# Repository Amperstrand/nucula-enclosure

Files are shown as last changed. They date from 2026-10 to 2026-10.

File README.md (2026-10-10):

# Nucula Enclosure — Rev 1 (no display / no keypad, optional pop-out screen)



Parametric, 3D-printable enclosure for the **Nucula board** (zeugmaster/nucula-board).
The KiCad board file is the single geometric authority: every board dimension in
this project is parsed from `nucula-v2.kicad_pcb` / its footprint libraries —
nothing is hand-transcribed.

Built with the methodology of the
[`Amperstrand/lilygo-a7670-simhat-carrier`](https://github.com/Amperstrand/lilygo-a7670-simhat-carrier/blob/cad/combined-carrier-v1/AGENTS.md)
project (its AGENTS.md lessons): measure first, boolean-volume
validation as the pass gate, calibration coupon before any real print,
renders are never evidence.

## Status (see `analysis/` for the machine-readable truth)

| Item | Status |
|---|---|
| Boolean validation | **80 / 80 checks PASS** (`analysis/interference_report.json`) |
| Deterministic rebuild | PASS (hash-identical STL on rebuild) |
| Physical print feedback | **NOT closed** — print `V0` coupon first |
| RF / battery measurements | **NOT taken** — `docs/MEASUREMENTS_NEEDED.md` |

## Variants (all from one parameter set — `cad/parameters.py`)

| Variant | Parts | Purpose |
|---|---|---|
| **V0** | `V0_calibration_coupon` | **Print FIRST.** Pilot-hole ladder, board-thickness stairs, real lip-bite bay, wire-lane slits, pop-out bridge feel |
| **V1** | `V1_bottom_shell` + `V1_lid_closed` | No screen, no keyboard (board broken away). Accessible USB-C + battery service bay |
| **V2** | `V1_bottom_shell` + `V2_lid_screen_popout` | Same print as V1's bottom; lid with a **pop-out OLED window printed closed** — pop it only if you fit the display glass |
| **V3** | `V3_bottom_shell_full` + `V3_lid_keyboard_blister` | Keyboard breakaway **NOT removed** (60×110 board). J3 keypad-header service blister with its own pop-out hatch |
| **V4** | `V4_bottom_shell_terminal` + `V4_lid_terminal` | **Payment terminal**: slim screen zone (landscape OLED window) + flared keypad zone with a bay that seats the Adafruit-1824-class 3×4 matrix keypad (70×50×7) over the breakaway section; J3 service opening in the bay floor |

Renders: `output/renders/OPTIONS_overview.png` (plus per-view PNGs and
`detail_*.png` close-ups). Renders illustrate; they are not evidence.

## Print order

1. `V0_calibration_coupon.stl` — calibrate (docs/printing.md)
2. `V1_bottom_shell.stl` + `V1_lid_closed.stl`
3. (optional) `V2_lid_screen_popout.stl`
4. (optional) `V3_bottom_shell_full.stl` + `V3_lid_keyboard_blister.stl`
5. (optional) `V4_bottom_shell_terminal.stl` + `V4_lid_terminal.stl` —
   payment-terminal layout: landscape screen on top, keypad bay (seats the
   Adafruit-1824-class 3x4 matrix keypad, 70x50x7) below over the breakaway
   section; J3 service opening in the bay floor.

## Regenerate everything

```sh
python3 scripts/extract_kicad_geometry.py   # KiCad -> analysis/*.json
python3 scripts/validate.py                 # 80 boolean checks -> interference_report.json
python3 scripts/build.py                    # STEP + STL -> output/exports
python3 scripts/render.py                   # PNG renders -> output/renders
```

Requires: Python 3.11+, `cadquery` ≥ 2.6 (2.8 verified — `requirements.txt`),
`playwright` + chromium (renders only).

**Portability:** the extracted geometry (`analysis/*.json`) is committed, so
`validate.py` / `build.py` work out of the box. Re-extraction from KiCad
needs the hardware repo: `NUCULA_REPO=/path/to/nucula-board
python3 scripts/extract_kicad_geometry.py` (defaults to
`~/my-project/reference-repos/nucula-board`).

## Layout

```
cad/parameters.py     ALL parameters + provenance tags + variant configs
cad/reference.py      board solids, component solids, keepouts, envelopes, wire sweep
cad/shell.py          bottom shell, lid (closed/popout/kb_blister), coupon
scripts/              extract / validate / build / render
analysis/             pcb_geometry.json, component_geometry.json,
                      interference_report.json, testing_status.json
output/exports/       STEP + STL per part
output/renders/       PNG renders + options overview
docs/                 design_spec, geometry_provenance, assembly, printing,
                      MEASUREMENTS_NEEDED, engineering_audit
reference/            ESP32 STEP (from the Nucula repo), three.js for renders
```

## Hard rules baked into the design

* The routed cut edge (v = 73) is **located, never clamped** — two stop ribs
  face the factory-routed windows *between* the mouse-bite remnant zones;
  the remnant envelope (2.0 mm stub + 0.30 mm spread) stays clear.
* **No metal anywhere.** Snap-fit lid (4 tabs), plastic plungers over
  RESET/BOOT, no inserts — nothing metallic near the NFC coil or the
  ESP32-C3 antenna.
* NFC: shell faces over the coil are ≤ `NFC_WALL_T` (1.6 mm); no structure
  above the coil plane inside the PCB's own antenna rule areas.
* Battery: pocket in the floor *behind* the ESP32/USB end (clear of the coil),
  swell clearance, wire route leaves the JST rear exit and drops through the
  remnant channel — all boolean-checked.
* USB-C: opening admits a fully-seated 13.0 × 6.5 mm plug envelope plus
  cable-bend service void — zero shell material inside it.

If you find a mechanical blocker in the *board*, do not "fix" it here —
record it in `docs/MEASUREMENTS_NEEDED.md`. The PCB is not modified by this
project.
## Photoreal hero render

Watch the V4 payment terminal assemble itself and spin:
**[nucula_hero.mkv](https://github.com/Amperstrand/enclosure-media/blob/main/nucula_hero.mkv)**
(+ stills) in [`Amperstrand/enclosure-media`](https://github.com/Amperstrand/enclosure-media) —
headless Blender/Cycles on GPU, built from these validated exports.

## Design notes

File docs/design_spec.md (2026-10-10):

# Design specification & audit — Nucula enclosure rev 1

Design intent in words, then the audit evidence for every sentence.
Evidence: `analysis/interference_report.json` (**57/57 PASS**, this run)
+ `analysis/testing_status.json`.

## Spec

1. **The unit houses one Nucula main PCB (keyboard breakaway removed,
   60 × 73 mm) or the full 60 × 110 board — never both at once.**
   Audit: `seated_board_bottom_interference = 0` for V1/V2 (main) and V3
   (full) beyond named lip contacts; `component_clearance` clean for all
   100+ placed parts in each mode.
2. **The board rests in a tray captured by retention lips on the three
   factory edges (u=0, u=60, v=0) and located — not clamped — at the
   routed cut edge by two stop ribs.**
   Audit: lips are the only board/bottom contact (INTENDED, subtracted);
   `cut_edge_located_not_clamped` (0.30 mm rib gap);
   `remnant_clearance = 0` (0.30 mm spread around every tab/bridge stub).
   No screws touch the board: it has no mounting holes, and every corner
   is adjacent to antenna/connector zones — snap-fit lid instead.
3. **NFC first.** Nothing metallic exists anywhere in the enclosure; shell
   faces over the 40 × 40 coil are ≤ 1.6 mm; no structure above the coil
   plane inside the PCB's own antenna rule areas.
   Audit: `nfc_battery_clear = 0`, `nfc_no_structure_over_coil = 0`,
   `nfc_reading_path_thin` (floor 1.4 / roof 1.4 / wall 1.6 ≤ NFC_WALL_T).
   Deliberate, documented: V2's glass hovers part of the rule area
   (dielectric) — `screen_glass_nfc_disclosure` + measurement item.
4. **ESP32-C3 antenna gets air.** The module's overhang clears through an
   open wall window (u 60.2..61.95, v 47..65.3, z 1.6..7.0); no battery or
   wiring in the antenna zone.
   Audit: `esp32_keepout_clear` (battery 0 / wires 0).
5. **USB-C accepts a fully seated common cable.** Opening = 13.0 × 6.5 mm
   plug envelope + 0.6 mm clearance + external lead-in chamfer; plug +
   overmold + cable-bend void (26 mm reach) contains zero shell material.
   Audit: `usb_envelope_clear = 0`, `usb_opening_size` (14.2 × 7.71 mm).
6. **The battery connector stays serviceable without tools.** A service bay
   in the left wall (46.3..54.2 v-band) exposes the JST PH housing; the
   lid snaps off; the battery pocket lives in the floor behind the
   ESP32/USB end, clear of both antennas, with swell + wire headroom.
   Audit: `battery_seat_clear = 0`, `wire_route_clear = 0` (JST housing
   contact INTENDED).
7. **Screen option is a printing decision, not a redesign.** V2's lid
   prints with the window closed behind a 1.0 mm pop-out panel (4 bridges
   + pick notch); pop it only when fitting the glass.
   Audit: `popout_panel_intact`, `screen_glass_fits` (0 part contact).
8. **Keyboard-attached variant keeps the future open.** V3 adds 37 mm of
   body, a factory-edge stop, and a J3 service blister with a pop-out
   hatch sized for a 1×9 2.54 mm header (8.7 mm).
   Audit: `j3_header_fits_blister = 0` with the header fitted.
9. **Prints flat, support-free, in PETG on a ~220 mm bed.** Largest part
   64.8 × 115.6 × 15.8 mm. Lid prints exterior-face-down (the pop-out
   panels and bridge walls print on the bed; the 1.7 mm roof step is the
   only small bridge).
10. **Every dimension is parametric and the model regenerates
    deterministically.** Audit: `build:deterministic_rebuild` PASS.

## V4 payment terminal (2026-10-10)

Layout: **screen on top, keypad below** (user directive; nucula-board
device orientation). The keypad is the board's intended peripheral: an
Adafruit-1824-class 3x4 matrix keypad (official outline 70x50x7, 7 scan
lines onto J3 pins 2-8; nucula-board keyboard-interface.md cites the
Adafruit 3845 arrangement).

Why a flared keypad zone instead of a flush cutout (elimination, all
boolean-probe driven):

* A flush through-cutout needs the keypad body (7 mm) INSIDE the cavity.
  The bottom zone has no 51 mm clean vertical span: J1 (USB, v 56..67,
  top z 6.7) and J3 + pigtail (v 104..111, top z ~12.1) bound it. A
*shallow* recess deeper than the 1.2 mm blister roof cuts into the J3
void. So the keypad sits OUTSIDE, in a bay: podium interior 12.4 mm
(clears J3 8.7 + pigtail), bay floor slab 1.4 mm, bay recess 3.0 mm.
* The 70 mm keypad exceeds the 64.75 mm slim case: the keypad zone
  flares +4.85 mm per side (outer 75.45) from the routed cut edge band
  (v 73.6) — vertical seam faces only, prints with the shell.
* Bay: u -5.6..65.6 (70 + 2x0.6 slack), v 58.8..110.0; rim 1.6; keys
  stand 4.0 mm proud of the rim (terminal look). Service opening
  u 18..42 x v 103.5..110 through the bay floor gives J3 tool access +
  the pigtail drop-through (no hatch needed: remove keypad to service).

Keypad geometry source: official Adafruit 1824 outline (datasheet text +
dimension drawing in the repo). A downloadable STEP of this exact part
exists (GrabCAD "adafruit-3x4-phone-style-matrix-keypad-1") but every
download path is login-gated; the render/validation stand-in uses ONLY
the official outline + a conservative 3x4 key grid, disclosed in
geometry_provenance.md. Replace with the real model when a login session
is available; the bay dimensions do not depend on it.

New checks (80 total): V4 runs the full matrix + `keypad_bay_admits_
stand-in` (official-outline solid seats without wall contact) +
`j3_service_opening_clear`.

## Known gaps (deliberate, documented)

- No physical print feedback yet — this release exists to close it (coupon first).
- Battery cell is a documented placeholder (30 × 22 × 6.0 mm).
- OLED glass outline/flex are conservative assumptions pending measurement.
- NFC range is the hardware repo's own open item; the enclosure adds a
  measured-later reading path (≤1.6 mm PETG everywhere over the coil).

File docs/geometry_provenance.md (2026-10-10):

# Geometry provenance

Every number used by the enclosure, and where it came from. Classes:
**extracted_kicad** (parsed from `nucula-v2.kicad_pcb` / footprint libs),
**derived_kicad** (computed from extracted geometry), **manufacturer_doc**
(Nucula repo doc or component drawing), **conservative_assumption**
(documented guess — measure before rev 2), **enclosure_design_decision**
(our choice — a changeable parameter).

## Board (all extracted_kicad / derived_kicad)

| Quantity | Value | Source |
|---|---|---|
| Outline | 60.000 × 110.000 mm | Edge.Cuts stitch, cross-checks docs/keyboard-breakaway.md |
| Thickness | 1.60 mm | `(general (thickness 1.6))` |
| Coordinate origin | KiCad (50, 50) = local (u0, v0) | derived from outline bbox |
| Main section | v 0..73 | routed gap edge (Edge.Cuts), matches keyboard-breakaway.md |
| Gap | v 73..75, corner r = 4 at both ends | Edge.Cuts |
| Support tabs | u 8.75..15.25 and 44.75..51.25 (rounded ends) | Edge.Cuts point-in-polygon |
| Central bridge | u 27.25..32.75 | inner slot boundaries |
| ESP32 antenna notch | u 55..60 × v 47.14..65.14 (18 × 5) | Edge.Cuts |
| Outer corner radii | r = 4 (all four corners) | Edge.Cuts arcs |

## Key components (bbox = pads+courtyard, derived_kicad)

| Ref | Part | u-extent | v-extent | Height | Height provenance |
|---|---|---|---|---|---|
| J1 | GCT USB4105-GF-A (USB-C) | −0.79..8.15 (shell face −0.80) | 56.42..67.36 | 3.31 | manufacturer_doc: GCT drawing |
| J2 | JST PH B2B-PH-SM4-TB | housing 2.39..10.0 (silk) | 46.82..54.98 | 5.60 | manufacturer_doc: JST drawing |
| DS1 | Hirose FH12A-24S-0.5SH | 21.2..38.8 | 53.6..61.6 | 2.00 | manufacturer_doc: Hirose drawing |
| U3 | ESP32-C3-WROOM-02-N4 (repo STEP) | 41.0..61.0 (antenna trace 54.92..60.57 overhangs the notch) | 47.14..65.14 | 3.20 | extracted_kicad: STEP bbox |
| U8 | PCF8574T (SOIC-16W) | 4.22..16.08 | 92.69..103.50 | 2.70 | conservative_assumption |
| J3 | 1×09 2.54 header (DNP) | 18.07..41.93 | 105.73..109.27 | 8.70 if fitted | conservative_assumption |
| SW1/SW2 | Omron B3U-1000P (RESET/BOOT) | centres (56.5, 34.0) / (56.5, 29.0) | — | 1.80 | conservative_assumption |
| D3 | Charge LED (0603) | centre (15.5, 44.0) | — | 0.70 | conservative_assumption |
| U1 | TP4054 (SOT-23-5) | 11.45..15.55 | 49.80..53.20 | 1.45 | conservative_assumption: JEDEC max |
| A1 | NFC coil (etched copper) | 10.75..50.75 | 1.00..41.00 | 0.035 | manufacturer_doc: 40×40 footprint property; cross-checked vs PCB rule areas |

## Keepouts / envelopes

| Zone | Extent | Provenance |
|---|---|---|
| NFC keepout | u 8.25..53.25 × v −1.5..43.5, all z | extracted_kicad: PCB antenna rule areas (verbatim) |
| ESP32 antenna keepout | u 52.0..61.5 × v 44.0..68.34, all z | derived_kicad trace bbox + 2.9 mm metal margin |
| USB plug envelope | mating face u −0.8, reach 26 mm, 13.0 × 6.5 plug | manufacturer_doc (GCT "6.5 Max", 12.x plug) + design decision |
| Battery pocket | u 7..55.6 × v 45.8..71.9, z −5.3..1.2 | enclosure_design_decision |
| Screen window (V2) | glass u 1.25..58.75 × v 16.6..46.0, LANDSCAPE, flex edge (+v short edge) folds ~12.9 mm to DS1 (24-pad row along u, panel pin 1 left / pin 24 right) | enclosure_design_decision + nucula-board device orientation (screen top, keyboard underneath); raised 2026-10-09 for the payment-terminal layout; NFP1309-02Y contact-edge side unverified |
| Remnant envelope | 3 stub zones + 0.30 spread, v 73..75.2 | enclosure_design_decision |

## Battery wire route (enclosure_design_decision)

J2 rear exit (u 10.0, v 50.9 ± 0.65, z = board_top + 2.0 per JST drawing)
→ −v corridor (J2 housing vs U1) → z 7.0 lane at u 19.2/20.6 (east of Q1,
west of the stop ribs, between remnant zones) → drop through the remnant
channel (v 73.58..75.08) → under-board run at z 0.78 → battery terminals.
Full-board mode: same start, z 7.0 over the whole keyboard section, drop
through the 2.0 mm channel at the factory edge v = 110.

## Heights not in the table

All unlisted SMD bodies use 1.00 mm (conservative_assumption: generic
passives ≤ 1.0). Change `COMP_HEIGHTS` in `cad/parameters.py` if your
build uses taller parts; the validator re-checks everything.

## V4 keypad (payment terminal)

| Quantity | Value | Source |
|---|---|---|
| Keypad class | Adafruit 1824/3844-class 3x4 matrix, 7 lines | manufacturer_doc + nucula-board docs/keyboard-interface.md |
| Outline | 70.0 x 50.0 x 7.0 mm, 23 g | manufacturer_doc: Adafruit 1824 datasheet |
| Key grid (stand-in only) | 3 cols x 4 rows, 10.8x9.2 caps +1.5 domes | conservative_assumption (render stand-in; official model download is login-gated - GrabCAD adafruit-3x4-phone-style-matrix-keypad-1) |
| Bay | u -5.6..65.6 x v 58.8..110.0, 3.0 deep | enclosure_design_decision (outline + 0.6 slack) |
| Zone flare | +4.85/side from v 73.6 (outer 75.45) | enclosure_design_decision |
| Podium interior | 12.4 (J3 8.7 + 0.5 + pigtail headroom) | enclosure_design_decision |
| J3 service opening | u 18..42 x v 103.5..110 in bay floor | enclosure_design_decision |

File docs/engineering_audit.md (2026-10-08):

# Engineering audit — requirement traceability

Method: boolean common-volume checks against the KiCad-derived reference
model (`analysis/interference_report.json`, 57/57 PASS). "mm³" = unexpected
common volume after subtracting named INTENDED contacts.

| # | Requirement | Verdict | Evidence |
|---|---|---|---|
| 1 | First build the authoritative PCB mechanical model from KiCad; no hand-transcribed dimensions | **met** | `scripts/extract_kicad_geometry.py`; 60×110 outline, 1.6 thickness, 131 footprints, tab/bridge/notch topology all parsed; cross-checked vs docs (keyboard-breakaway.md, nfc-antenna.md) |
| 2 | Main PCB = board after keyboard separation (~60×73) — verified programmatically | **met** | Edge.Cuts point-in-polygon: main section v 0..73; tabs/bridge remnant zones mapped |
| 3 | Keep KiCad orientation as the global frame | **met** | board-local (u,v) = KiCad (X−50, Y−50); transform documented in extract script |
| 4 | No OLED window, no keypad openings in the base design | **met** | V1 lid closed; V2 window is an optional pop-out (user decision); V3 hatch is service-only |
| 5 | Cut edge never used for tight location; prefer factory edges | **met** | stop ribs at 0.30 mm gap facing routed windows between remnant zones; v=0/u/u=60 edges + pocket rim carry the rest |
| 6 | PCB retention without mounting holes; no force on parts/solder/USB/battery/NFC | **met** | 3-edge lips (0.65 overhang, INTENDED contact), 4 corner under-board pads on bare laminate, pocket rim locators, stop ribs; `seated_board_*` + `component_clearance` = 0 |
| 7 | NFC keepout: 3D, no battery/screws/inserts/magnets/metal above or behind the coil | **met** | `nfc_battery_clear`, `nfc_no_structure_over_coil`, snap-fit + plastic plungers; disclosure: V2 glass partially overlays the rule area (dielectric, measured later) |
| 8 | Thin wall adjacent to coil (NFC_WALL_T, 1.2–2.0) | **met** | all shell faces over the coil ≤ 1.6 (`nfc_reading_path_thin`) |
| 9 | ESP32 antenna keepout, plastic-only | **met** | `esp32_keepout_clear`; plus an open wall window so the overhang clears |
| 10 | Battery: conservative placeholder, swell allowance, wide pocket (no point clamps), wire routing without pinch, away from both antennas | **met** | pocket 47.5×26.1×7.5 void for a 30×22×6 cell; `battery_seat_clear`, `wire_route_clear`, `esp32_keepout_clear`, `nfc_battery_clear` |
| 11 | USB-C real mating envelope, full insertion, zero intersection, external chamfer, wall strength | **met** | `usb_envelope_clear = 0`, `usb_opening_size` (14.2 × 7.71), lead-in chamfer, bay is wall-local |
| 12 | Buttons: derive function, then regular access or tool hole | **met** | SW1 RESET / SW2 BOOT (net-derivable, BOM value) → recovery use → Ø3.2 ports + moulded plastic plungers |
| 13 | Fastening: simplest reliable, metal away from antennas, boss clearances verified | **met (deviation documented)** | snap-fit lid chosen OVER screws: the board has no holes, all four corners are antenna/connector-adjacent, and boss shafts could not clear the corner voids (r4) without two-tier posts. Screws would violate "metal away from antennas" or need bosses inside component zones. Coupon retains a pilot ladder if a future rev wants screws |
| 14 | Coupon reuses production geometry | **met** | `shell.coupon()` consumes RAIL_LIP_*, SCREEN_BRIDGE_*, slit ladder |
| 15 | Automated validation incl. INTENDED/FAILURE classification | **met** | 57 checks; intended contacts named (lips, J2 wire exit, plunger hover); deterministic-rebuild check included |
| 16 | Renders as illustrations, close-ups for feature verification | **met** | `output/renders/OPTIONS_overview.png` + 15 per-view PNGs + 5 detail PNGs |
| 17 | Machine-readable reports | **met** | `interference_report.json`, `testing_status.json`, `parts_manifest.json`, `render_manifest.json` |
| 18 | Deliver STEP + STL + docs | **met** | `output/exports/*.step|stl` (8 parts), this docs set |
| 19 | Variants: calibration / minimal (USB+battery access) / screen pop-out / keyboard-attached | **met** | V0/V1/V2/V2b/V3 all built, validated, rendered |
| 20 | Testing status visible everywhere | **met** | `testing_status.json` + README matrix: boolean-verified vs requires-physical-print vs requires-measurement |
| 21 | PCB not modified; blockers recorded, not "fixed" | **met** | `docs/MEASUREMENTS_NEEDED.md` board-side section |
| 22 | Reusable architecture for future revs (display/keypad versions) | **met** | parameters + provenance + validation framework are variant-driven; `screen_window`/`kb_blister` flags already implement the extension points |

## Deviations from the original brief (documented)

1. **Snap-fit instead of screws** (req. 13): reasons above; reversible by
   setting `SCREW_*` params and re-adding posts in a rev-2 branch.
2. **ESP32 antenna wall window**: brief said "plastic-only in the zone" —
   the open slot goes further (air path) because the module overhangs the
   board edge by 1.0 mm and a closed 1.6 mm wall would collide; RF-wise
   it is the better reading environment. Measure (item 7).
3. **Battery under the board, connector end** (not beside the board):
   keeps the case 60 mm wide (wallet-like); the wire route threads the
   JST rear exit, the remnant channel and the under-board gap — all
   boolean-verified. If the real cell exceeds 30 × 22 × 6, the pocket
   grows and the case thickens — parameters handle it.

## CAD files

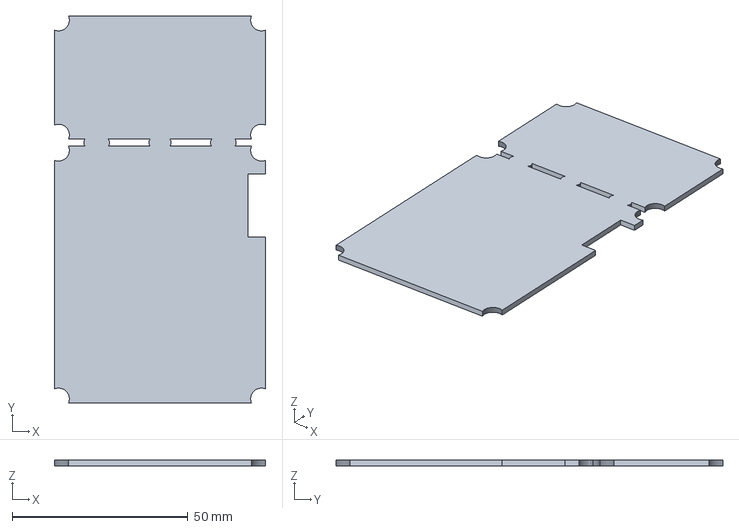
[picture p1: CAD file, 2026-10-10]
output/exports/reference_full_board.step
60.0 x 110.0 x 1.60 mm

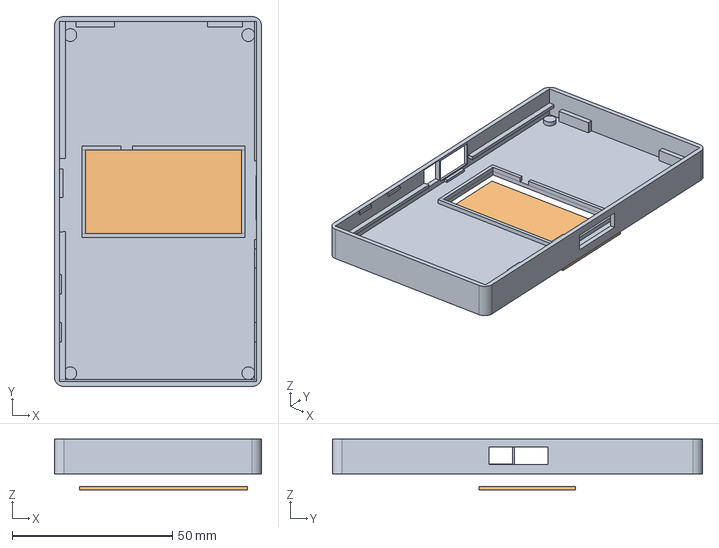
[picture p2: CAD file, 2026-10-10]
output/exports/V3_bottom_shell_full.step
64.8 x 115.5 x 15.8 mm

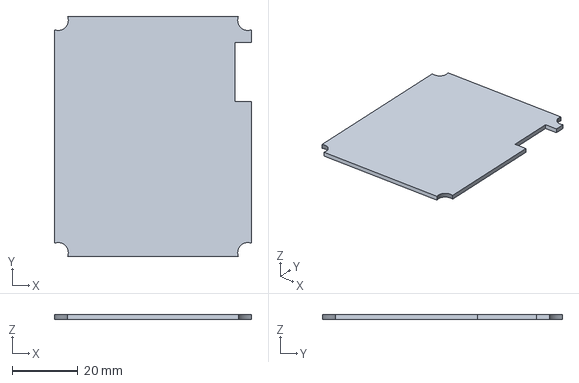
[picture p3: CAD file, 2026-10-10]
output/exports/reference_main_board.step
60.0 x 73.0 x 1.60 mm

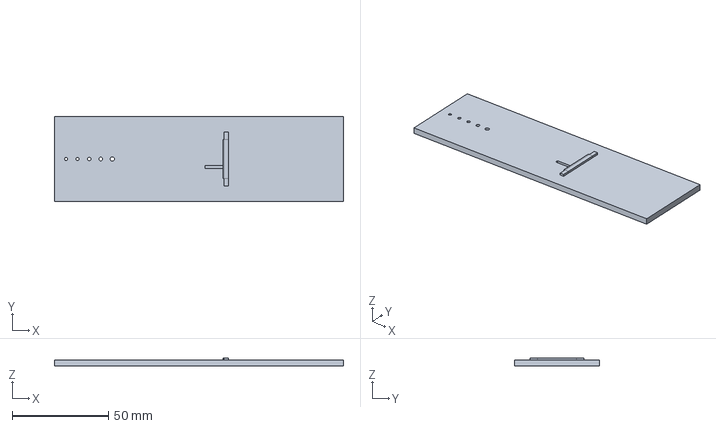
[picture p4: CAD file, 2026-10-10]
output/exports/V0_calibration_coupon.step
150.0 x 44.0 x 4.30 mm

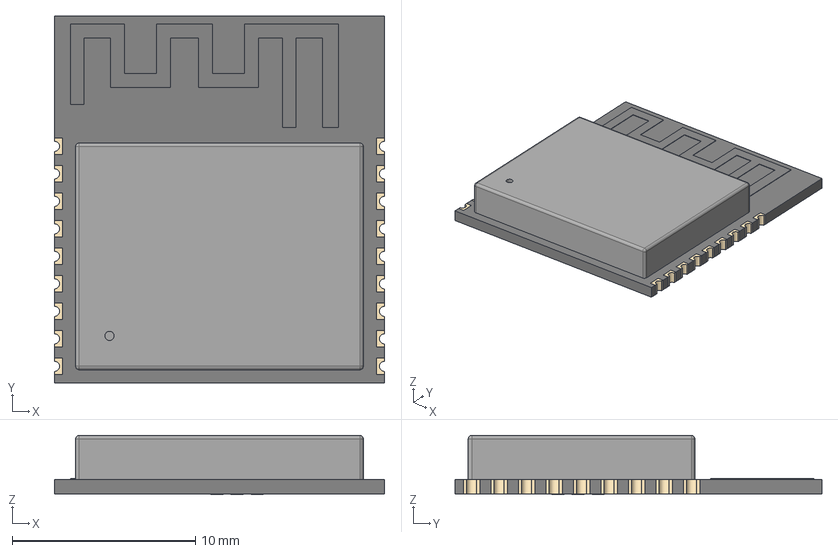
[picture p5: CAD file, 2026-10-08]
reference/ESP32-C3-WROOM-02-N4.step
18.0 x 20.0 x 3.24 mm

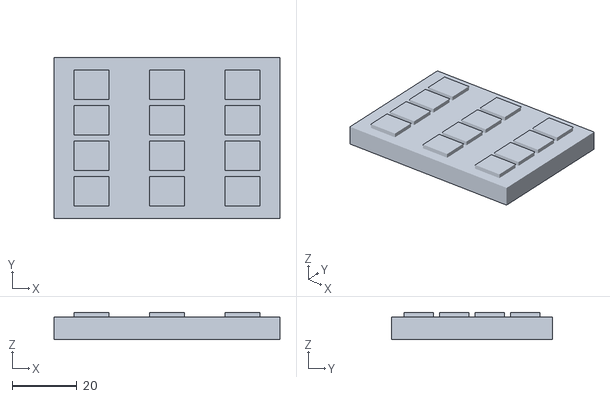
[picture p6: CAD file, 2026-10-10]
output/exports/keypad_standin.stl
70.0 x 50.0 x 8.50

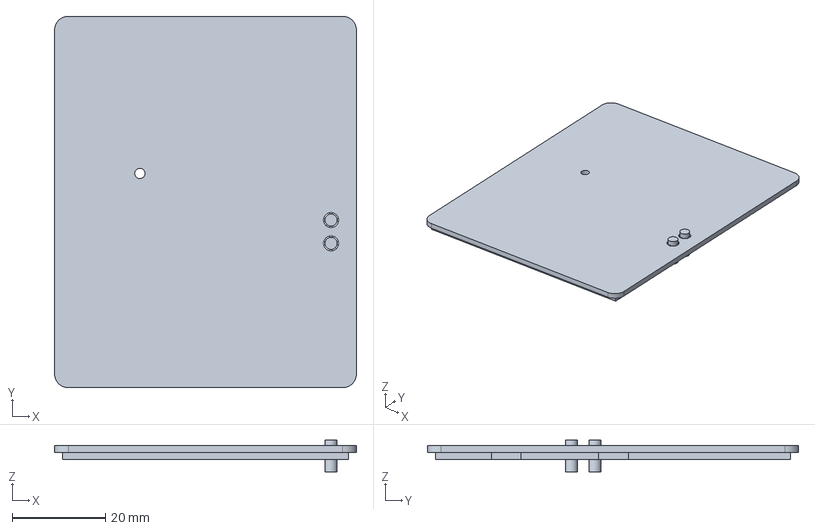
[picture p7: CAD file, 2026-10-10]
output/exports/V1_lid_closed.step
64.8 x 79.7 x 6.80 mm

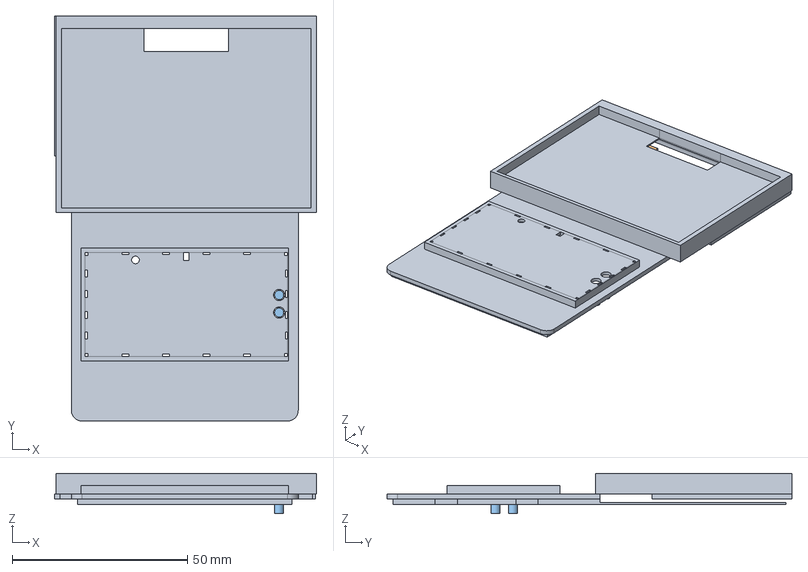
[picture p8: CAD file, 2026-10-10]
output/exports/V4_lid_terminal.step
74.9 x 115.6 x 11.5 mm

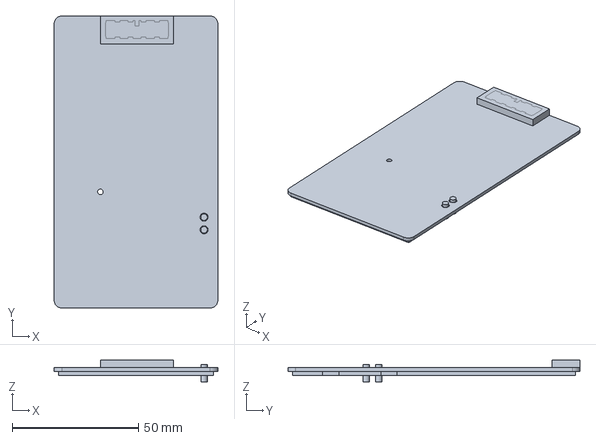
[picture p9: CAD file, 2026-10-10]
output/exports/V3_lid_keyboard_blister.step
64.8 x 115.6 x 8.60 mm

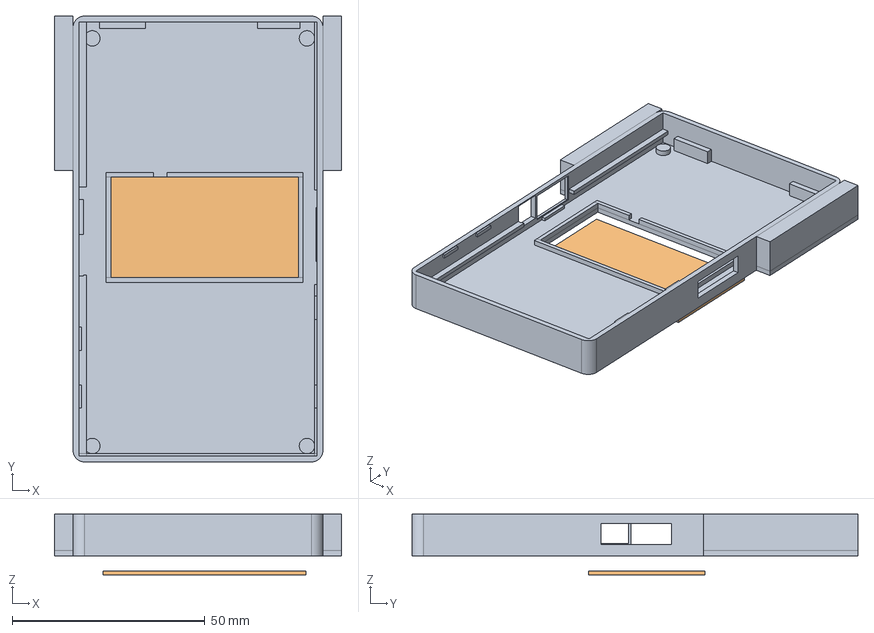
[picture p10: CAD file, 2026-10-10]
output/exports/V4_bottom_shell_terminal.step
74.5 x 115.5 x 15.8 mm

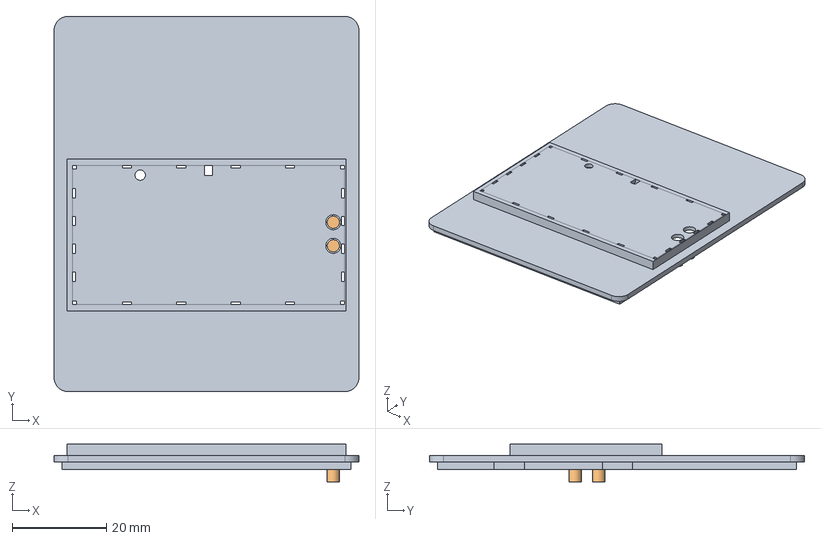
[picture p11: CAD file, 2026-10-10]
output/exports/V2_lid_screen_popout.step
64.8 x 79.7 x 8.05 mm

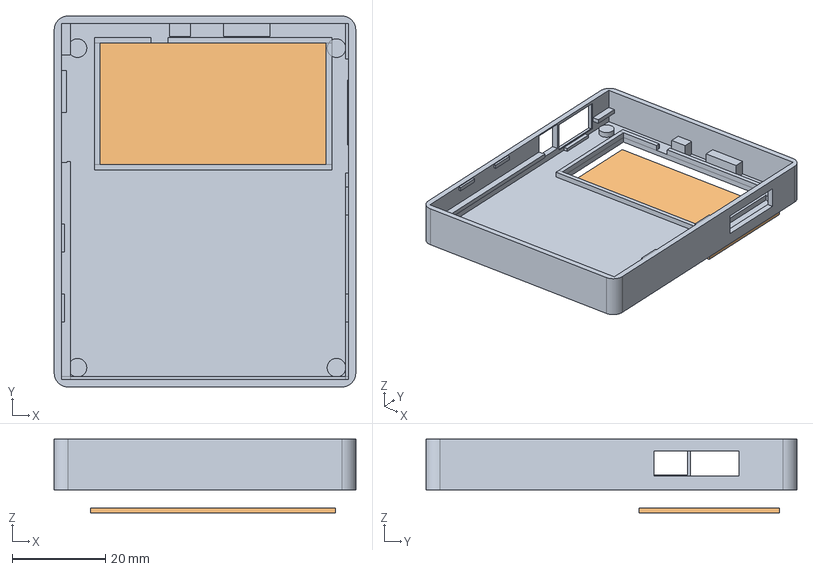
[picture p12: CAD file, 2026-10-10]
output/exports/V1_bottom_shell.step
64.8 x 79.7 x 15.8 mm

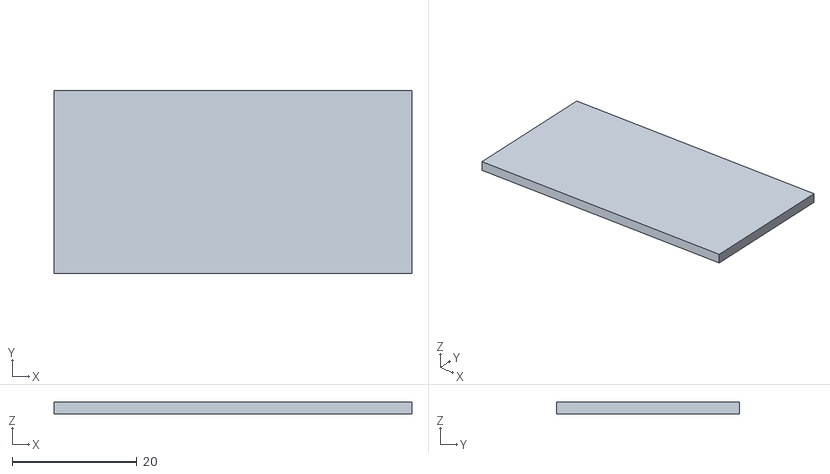
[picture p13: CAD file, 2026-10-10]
output/exports/glass.stl
57.5 x 29.4 x 1.90

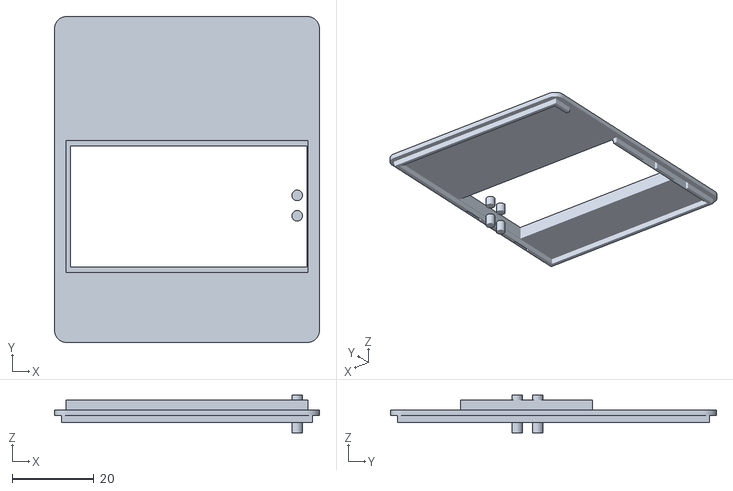
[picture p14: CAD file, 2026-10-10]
output/exports/V2_lid_screen_popped.stl
64.8 x 79.6 x 9.25

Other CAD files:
output/exports/battery.stl
output/exports/V0_calibration_coupon.stl
output/exports/V1_bottom_shell.stl
output/exports/V1_lid_closed.stl
output/exports/V2_lid_screen_popout.stl
output/exports/V3_bottom_shell_full.stl
output/exports/V3_lid_keyboard_blister.stl
output/exports/V4_bottom_shell_terminal.stl
output/exports/V4_lid_terminal.stl
output/exports/reference_full_board.stl
output/exports/reference_main_board.stl

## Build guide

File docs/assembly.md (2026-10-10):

# Assembly guide — Nucula enclosure rev 1

Reference renders: `output/renders/detail_battery_pocket.png`,
`detail_usb_battery_ports.png`, `OPTIONS_overview.png`.

## What you need

* Printed parts (docs/printing.md): V1 bottom + V1 or V2 lid (V3 set for
  the keyboard-attached variant).
* Nucula board, keyboard section separated (docs/keyboard-breakaway.md of
  the hardware repo: cut the central bridge FIRST, then snap the tabs,
  trim remnants).
* 1S LiPo/Li-ion pack that fits the pocket (placeholder 30 × 22 × 6 mm),
  with a JST PH plug crimped.
* Optional display kit: SSD1309 2.42" glass + 24-way 0.5 mm FFC jumper
  (≥25 mm), only for the V2 lid with the window popped.

## Bottom shell preparation

1. Inspect the battery pocket (floor, behind the USB end): no strings,
   the pocket rim sits 0.15 mm below the board underside plane.
2. Dry-fit the board: NFC end (v=0) under its lip first, then roll the
   cut edge over the two stop ribs. The lips on u=0 (interrupted at the
   service bay + USB), u=60 (interrupted at the antenna window) and v=0
   should all capture. The board must NOT rest on any component — only
   lips, corner pads, rim locators.
3. Battery wires: harness exits the JST housing rear (toward +u),
   climbs into the z≈7 lane, runs the u≈19/21 lane to the cut edge,
   drops through the remnant channel between the stop ribs, then runs
   under the board to the pocket. Leave slack at the housing for the
   2.6 mm bend radius.
4. Plug the harness onto J2 (top-entry). The left-wall service bay gives
   finger access if you ever need to unplug without opening the case.

## Board + lid

5. Seat the board (step 2). Check: USB connector face aligns with the
   wall opening; JST housing visible in the service bay; charge LED under
   the Ø2.2 lid hole.
6. Fit the lid: lip under all wall tops, then press the four snap tabs
   (left wall v≈15/30, right wall v≈15/38). Open again by prying the
   lid edge at the NFC-end corner notch.

## V2 display option

7. Pop the window panel from the INSIDE (push the pick notch; the four
   bridges snap). Trim nubs flush. The window is LANDSCAPE, 57.5 x 29.4,
   flex edge on the socket-side short edge.
8. Adhesive-mount the glass on the four standoff pads under the window,
   emitting face toward the opening.
9. Glass flex → FFC jumper → route under the glass → fold down at
   DS1 → insert into the FH12 socket (contacts face the flex).
10. Before closing, power over USB and confirm the display; then snap
    the lid.

## V3 keyboard-attached option

* Same steps with the full 60×110 board; the keyboard section lives
  under the long roof. The J3 service blister + hatch stay closed until
  you fit a keypad header (then pop the hatch, fit the header through
  it, and the blister provides the 8.7 mm clearance).

## Checks after first assembly

* USB cable inserts fully, no wall contact (validated envelope).
* Buttons click through the plungers (0.3 mm gap to the B3U actuators).
* NFC read with a card on the lid over the coil half of the case.
* Battery unplugs through the service bay with the lid on.

## V4 payment terminal (keypad)

10. Seat the 3x4 matrix keypad (Adafruit-1824-class, 70x50x7) into the
    bay from the outside; its back rests on the bay floor, keys stand
    ~4 mm proud. Fix with the keypad's adhesive back or VHB dots.
11. Run 7 female-female jumpers from the keypad's top-edge pins through
    the bay-floor service opening onto J3 pins 2-8 (pin 1/9 NC). ~60 mm
    leads; all wiring stays inside the podium void.
12. J3 service = peel/lift the keypad; the opening (u 18..42) clears the
    full header for fitting and probing.

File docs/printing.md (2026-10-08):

# Printing guide (PETG assumed)

## Order

1. **V0 calibration coupon** (`V0_calibration_coupon.stl`, 150 × 44 × 4.3 mm,
   ~6 g) — print FIRST, calibrate, THEN trust the shells.
2. V1: `V1_bottom_shell` + `V1_lid_closed`
3. Optional: `V2_lid_screen_popout` (bottom is shared with V1)
4. Optional: `V3_bottom_shell_full` + `V3_lid_keyboard_blister`

## Coupon interpretation

| Bay | Feature | What to check |
|---|---|---|
| A | Ø 1.55 / 1.70 / 1.85 / 2.00 / 2.20 holes | spare self-tap pilots; find the clean-thread size |
| B | 1.2 / 1.4 / 1.6 / 1.8 mm tunnels (2.2 below top) | slide a board scrap: the 1.6+mask laminate must pass |
| C | production lip over a 1.6 mm slot | lip bite feel = the real board retention feel |
| D | 0.30 / 0.40 / 0.50 / 0.60 mm slits | wire-lane clearance pick |
| E | pop-out panel with 3 bridges | snap the panel out: bridge strength + pick feel |

## Settings (starting points)

* Material: PETG (never PLA for the snap tabs/lid).
* Nozzle 0.4, wall `WALL_T = 1.6` = 4 perimeters; top/bottom `FLOOR_T`/`ROOF_T`
  = 1.4.
* Layer 0.2 mm.
* **Bottom shell: print as-is (z=0 face on the bed)** — the battery bump
  forms a shallow open bowl on the bed; no supports.
* **Lid: print exterior-face-down** — the pop-out panel(s) and their
  bridges print flat on the bed; the 1.7 mm general-roof step around the
  V2 deck is the only bridge and is edge-anchored.
* Cooling: moderate; the pop-out bridges need to solidify before the deck
  walls run over them.
* Infill: 25 % gyroid is plenty; the structure is walls.

## Post-processing

* V2: to fit the display — pop the window panel (push the pick notch on
  the inside face), trim the hinge nubs, glue the glass to the lid
  underside on the four included standoff pads, connect the glass flex to
  a 24-way 0.5 mm FFC jumper, route it under the glass and plug it into
  DS1 (flex route validated in `screen_glass_fits`).
* V3: the J3 hatch pops the same way when you decide to fit a keypad header.
* Deburr the mouse-bite remnants on the PCB before the first fit; the case
  tolerates 2.0 mm stubs + 0.30 mm spread but cleaner is better.

## Assembly

1. Battery into the floor pocket, wires routed: JST rear exit → over the
   board top lane (z 7 channel) → remnant-channel drop → under-board run →
   battery terminals. The lane is boolean-validated (`wire_route_clear`).
2. Plug the JST housing onto J2 (reachable through the left-wall service
   bay).
3. Board into the tray: NFC end first under the v=0 lip, then roll the
   cut edge over the stop ribs; the lips snap over the edges.
4. Lid: lip under the wall tops, press the 4 snap tabs (pry at the NFC-end
   corner notch to open).
5. RESET/BOOT: press the moulded plungers through the roof holes.

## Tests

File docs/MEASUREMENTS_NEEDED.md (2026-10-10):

# MEASUREMENTS_NEEDED.md

Physical inputs this design assumed or deferred. Rev 2 should fold each
answer back into `cad/parameters.py` and re-run `scripts/validate.py`.

| # | Unknown | Current assumption | How to measure | Blocks |
|---|---|---|---|---|
| 1 | Battery cell L × W × T | 30 × 22 × 6.0 mm (LP-series-ish placeholder) | calipers on the chosen protected 1S cell | pocket fit, bump depth, case thickness |
| 2 | Battery wire gauge + JST harness length | 2 × Ø1.3, PH housing rear exit at 2.0 mm | calipers + the real harness | wire lane, service bay reach |
| 3 | NFC range, closed case (coil + lid + battery) | unknown (hardware repo's own open item) | card + PN7160 read-log distance, lid on, battery in | rev-2 wall/floor thinning |
| 4 | NFC impact of the V2 glass over part of the coil rule area | dielectric, tolerated | repeat measurement 3 with the glass fitted | V2 viability as-is |
| 5 | OLED glass outline | 57.5 (u-long) × 29.4 × 1.9 mm (2.42" SSD1309 candidate, LANDSCAPE) | calipers on the real glass (QDtech OLED242W ordering code unconfirmed in the repo) | window + deck size |
| 6 | NFP1309-02Y flex length + contact-edge side | 12 mm assumed; flex on the +v short edge, design plans a 25 mm FFC jumper | measure the flex; confirm which short edge carries the 24 contacts; buy a 24-way 0.5 mm jumper | display assembly |
| 7 | ESP32-C3 TRP with the open wall window | expected better than closed wall | range/throughput test vs bare board | keep/discard the window |
| 8 | Mouse-bite remnant geometry after the user's cut | ≤2.0 mm stub, ±0.30 spread | calipers after the first real separation | end-wall gap, stop-rib windows |
| 9 | Snap-tab retention force | unmeasured | pull test on the first print | tab count/size |
| 10 | Lip bite feel on the real 1.6 mm laminate | 0.65 mm overhang, 1.1 mm lip | coupon bay C squeeze test | RAIL_LIP_OVERHANG |
| 11 | USB plug boots in the wild | 13.0 × 6.5 envelope + 0.6 clearance | plug 3-5 common cables fully | opening size |
| 12 | Charge-LED visibility through the V2 deck hole | dim (3+ mm deep hole) | eyeball with the board powered | LED window shape / light pipe |
| 13 | J3 blister usability with a real keypad cable | hatch 26 × 5.5 mm | dry-fit a 3×4 matrix keypad pigtail (Adafruit PID 3845-class, 7-line + 2 NC) | hatch size |
| 14 | Real keypad outline vs 70×50×7 assumption | Adafruit 1824 datasheet (stand-in basis) | caliper the purchased keypad before printing V4; bay = outline + 0.6 | V4 bay fit |
| 15 | Keypad key pitch / cap size (stand-in cosmetic only) | 10.8×9.2 caps, conservative | measure once a real keypad is at hand; affects renders, not the bay | stand-in fidelity |
| 16 | Fetch the real 1824 STEP | login-gated (GrabCAD adafruit-3x4-phone-style-matrix-keypad-1) | download with an account; replace cad stand-in | render realism |

## Board-side observations (do NOT fix here)

* The JST PH housing (5.6 mm) sets the interior height — a lower battery
  connector on a future PCB rev would drop the case ~3 mm.
* **Board-rev drift (2026-10-09): the nucula-board repo's current rev has
  J2 as a JST SH SM02B side-entry connector opening toward the LEFT edge
  (u=0), not the PH rear-exit this enclosure was extracted from; it also
  adds six M2 holes (four main-board + H5/H6 on the keyboard section) and
  J6 direct battery wire pads.** Re-run `scripts/extract_kicad_geometry.py`
  against the current board before the next print; the battery wire route
  and the left-wall service slot will need re-derivation for a side-entry
  J2.
* The display socket faces the NFC coil; the landscape glass (v ~23.6..53)
  overhangs the coil rule area's lower band (disclosed dielectric). A
  shorter glass or a more keyboard-side flex edge trades display area for
  NFC aperture.
* M2 holes now exist on the board (see drift note); screw bosses remain
  REJECTED while "no metal near the coil" stands — revisit only with
  plastic screws or a board rev that moves the holes clear of rule areas.

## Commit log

2026-10-08 feat: nucula enclosure rev 1 — import
    Parametric 3D-printable enclosure for the Nucula board (zeugmaster/
    nucula-board): KiCad file is the geometric authority, 57-check boolean
    validation, variants V0-V3, calibration coupon first. Imported as
    built (pre-fix state; see next commits).
    Ultraworked with [Sisyphus](https://github.com/code-yeongyu/oh-my-openagent)
    [ESP32-C3-WROOM-02-N4.step, V0_calibration_coupon.step, V0_calibration_coupon.stl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]
2026-10-08 fix(render): placeholder STLs load from exports/; loader errors fail fast
    build_placeholders() writes battery.stl/glass.stl into output/exports/,
    but scene parts with file=None built output/renders/<tag>.stl URLs that
    nothing wrote — the shipped renders only worked because stale copies sat
    in renders/. Fresh clones hung 5 min in wait_for_function (STLLoader had
    no error callback). Now parts_json() resolves None -> PLACEHOLDERS[tag]
    (single source: exports/), the loader sets document.title=LOAD_ERROR and
    render.py raises on it. Stale renders/*.stl removed; full render set
    regenerated and re-audited (luminance/size profile matches shipped set).
    Trap recorded in AGENTS.md.
    Ultraworked with [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
    [battery.stl, glass.stl]
2026-10-08 ci: boolean validation workflow (57 checks) + pinned requirements
    analysis/*.json are committed, so CI needs no KiCad source; OMP pinned
    per the OpenCascade-on-CI thread-race lesson from the carrier project.
    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
2026-10-08 docs: standalone README — CI badge, methodology link, verified deps
    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
2026-10-09 fix(screen): landscape OLED window, screen above keyboard (nucula-board orientation)
    The V2 window was portrait (57.5 along v, flex edge at the routed cut
    edge): every boolean check passed, but the device is held keyboard-down
    with the screen at the top (user + nucula-board docs: DS1 pad row runs
    along u, mounted panel pin 1 left / pin 24 right => landscape glass).
    Now: glass 57.5 (u) x 29.4 (v), flex edge = the +v short edge at the DS1
    courtyard (SCREEN_FLEX_EDGE_V=53.0, SCREEN_CENTER_U=30 from DS1), screen
    band v ~23.6..53 sits above the keyboard-side cluster. Deck ring derives
    from the window + SCREEN_DECK_BEZEL (was hardcoded). RESET/BOOT ports
    re-cut through ring + pop-out panel with p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
2026-10-09 chore: regenerate analysis + exports + renders for the landscape window
    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
    [V0_calibration_coupon.step, V1_bottom_shell.step, V1_lid_closed.step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]
2026-10-10 docs: point to Amperstrand/enclosure-forge for the general methodology
    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
2026-10-10 feat(screen): window raised to v 16.6..46.0 (payment-terminal layout, iteration 1)
    Flex edge v 46.0: ribbon fold ~12.9 mm to DS1 matches the 12 mm NFP1309-02Y assumption; glass now clears J2 and the ESP32 entirely (only low parts beneath). Coil-rule disclosure grows to v 16.6..41 (documented). 57/57 PASS; renders + exports regenerated.
    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
    [V0_calibration_coupon.step, V1_bottom_shell.step, V1_lid_closed.step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]
2026-10-10 feat(V4): payment-terminal variant — screen raised, keypad bay over breakaway section
    Layout per user directive + nucula-board device orientation: landscape
    screen at top (raised to v 16.6..46.0 in the slim zone), keypad below.
    Keypad = the board's intended peripheral (Adafruit-1824-class 3x4
    matrix, J3 pins 2-8): official outline 70x50x7. Elimination by boolean
    probes ruled out a flush cutout (J1 + J3/pigtail bound the bottom zone;
    51 mm clean span does not exist), so the keypad seats in an exterior
    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
    [V0_calibration_coupon.step, V1_bottom_shell.step, V1_lid_closed.step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]
2026-10-10 docs: link photoreal hero render (enclosure-media)
    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
2026-10-11 feat(V5): product polish — raised keypad, chamfered Square-style shoulder, rounded podium, thin bezel (80/80)
    Bay depth 3.0->2.0 (keys 5 mm proud, 'raised a little'); the flare step
    becomes a sloped lofted shoulder (cavity cut out of the wedge - the
    filled-loft bug was caught by 4 red checks, U8 345 mm3 arithmetic);
    vertical-edge corner radii only (2D-print-safe, no top rounding); bezel
    1.30->1.10. Keypad class re-confirmed against nucula-board docs: the
    3845 citation pins the ELECTRICAL order; membranes (70x77) are
    eliminated by OLED-window arithmetic; the 1824-class hard pad stands.
    Ultraworked with [Sisyphus](https://github.com/code-yeongyu/oh-my-openagent)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
2026-10-11 feat(V6): uniform slab variant — one flat face, everything flush (104/104)
    Square/SumUp-class silhouette: uniform 74.45-wide walls full length,
    single top plane at keypad-face height (screen + keypad well flush,
    keys proud <=1.6), NFC membrane legal by construction (new
    nfc_membrane_slab check), no flare/podium/deck-ring. V2 positioned as
    the dry minimal option. Artifact-proven: lid zmax = bay_floor+KEYPAD_T
    exactly; ring overshoot caught by the z-probe and fixed.
    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
2026-10-11 feat: modular config system (any feature combination) + in-browser configurator on Pages
    cad/config.py: board/screen/keypad/battery/usb/profile flags with
    constraint enforcement; build.py --config / --matrix (8 prebuilt
    configs, 16 parts, all from the validated builders - feature gating in
    bottom_shell/slab_*); gh-pages configurator (three.js, config picker,
    Show PCB / lid / keypad toggles) at amperstrand.github.io/nucula-enclosure.
    Validation unchanged: 104/104.
    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
